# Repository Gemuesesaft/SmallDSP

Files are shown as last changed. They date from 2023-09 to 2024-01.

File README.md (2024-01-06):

# SmallDSP
a small, modular and affordable Audio DSP Module

The goal of this Project is to create a line-up of small DSP modules, centred
around an Analog Devices ADAU1463/67.
This Chip is easy to program with Sigma Studio, a node based development 
environment and pretty powerful for its price.

Current status:
- Dual: Rev 1.1: Layout finished, functionality has to be validated.
- Maxi: Rev 1.0: Layout finished, ,prototype ordered, 
    functionality has to be validated.
- Multi: Rev 1.0: Schematic unfinished.
- Mini: Nothing done yet.
- Micro: Nothing done yet.
- Digi: Nothing done yet.

I've planed for 6 different modules:

- A compact one with two analogue input and output channels (SmallDSP Dual).
- A very small with only digital I2S IOs (SmallDSP Digi).
- A very small module with only one analogue input and output (SmallDSPMini).
- A similar than the Mini, but with and Microphone preamp (SmallDSP Micro). 
    Perhaps powered by phantom power.
- One with 16 analogue IOs (SmallDSP Multi).
- And one with 32 analogue IOs (SmallDSP Maxi).

There are three different versions of the used DSP Chip:
- The ADAU1463WBCPZ150. This is a slower version (max. 150MHz) with 48kWords 
    data memory and 16kWords program memory. Optimal for the smaller Boards
    like the Dual, Mini or Micro.
- The ADAU1463WBCPZ300. This is a faster version (max. 300MHz) with the same
    48kWords data memory and 16kWords program memory. Well suited for heavy
    processing or many channels, for example the Multi or Maxi.
- And the ADAU1467WBCPZ300. This is also a faster version (max. 300MHz) with
    more memory 80kWords data and 24kWords program memory. The expanded memory
    is useful if long delays on multiple channels are required.
All versions are pin-compatible, so one can use the version, best suited for 
the use case. 

The Dual, Digi, Mini and if phantom power isn't possible, the Micro, shall be
powered by a single output wall brick power supply. Both Multi and Maxi are 
using a +-5V power supply and feature a PE connection. They are therefore
designed for a metal enclosure such a 19" Rack enclosure. 

I try to maximize the components covered by JLCPCBs Basic Parts library, so
the boards can be manufactured cheaply and easily. Unfortunately this doesn't
cover all components, so there is still some hand soldering necessary. 

I tried to avoid the use of a Microcontroller, because the DSP can do pretty
much everything on itself. Although the DSP can act as a I2C or SPI master, I 
used ADCs and DAC that are configured directly by setting specific pins,
because the usage of the I2C/SPI master feature an ADAU DSPs is, at least
to my knowledge, not very user-friendly. Please correct me if I'm wrong there 
I would very much like to know an easy way to use this feature.
The Maxi is an exception in that, as it has a STM32 MCU on board. That is 
because the used Codecs are only controllable over I2C/SPI and are way cheaper
than pin-controllable alternatives.

A detailed documentation is planned, but the current focus lies on finishing
the PCBs and the testing of those. Detailed performance measurements will
be published here as well, as soon as they are made.

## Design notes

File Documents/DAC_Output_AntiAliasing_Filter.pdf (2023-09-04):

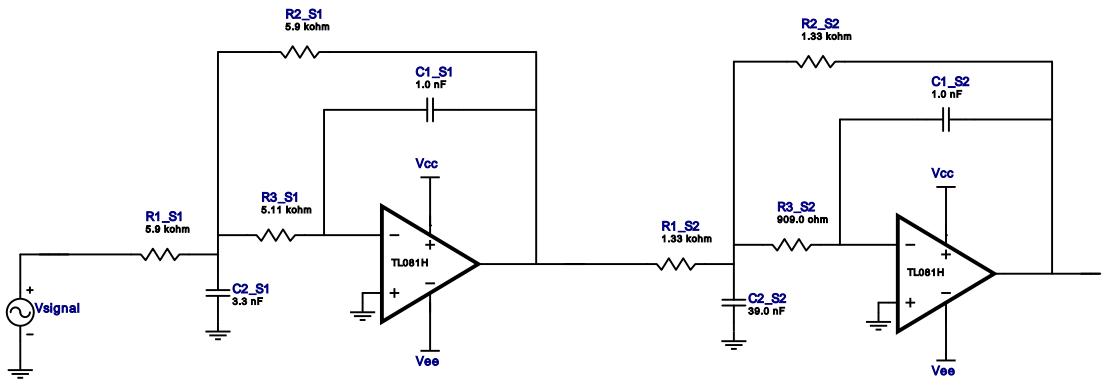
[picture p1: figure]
Vsignal; R1_S1 5.9 kohm; R2_S1 5.9 kohm; R3_S1 5.11 kohm; Vcc; Vee; R1_S2 1.33 kohm; R2_S2 1.33 kohm; R3_S2 909.0 ohm

Copyright © 2023, Texas Instruments Incorporated | 1
Filter Design Report | Lowpass Filter - 4th order Chebyshev | September 3, 2023 10:54:27 GMT-05:00

## Filter Design Report

Design : Lowpass Filter - 4th order Chebyshev Design ID: 142

Type : Lowpass
Response : Chebyshev
Order : 4
Number of Stages : 2

## Electrical BOM

# Name | Manufacturer | Part Number | Properties | Qty

1. A1_S1 | Texas Instruments Inc. | TL081H | GbwTyp= 5.25MHz VccMax= 40V VccMin= 4.5V | 1
2. A1_S2 | Texas Instruments Inc. | TL081H | GbwTyp= 5.25MHz VccMax= 40V VccMin= 4.5V

1

3. C1_S1 | Generic | Ideal | Cap= 1.0 nF Tolerance= 5.0 %

1

4. C1_S2 | Generic | Ideal | Cap= 1.0 nF Tolerance= 5.0 %

1

5. C2_S1 | Generic | Ideal | Cap= 3.3 nF Tolerance= 5.0 %

1

6. C2_S2 | Generic | Ideal | Cap= 39.0 nF Tolerance= 5.0 %

1

7. R1_S1 | Generic | Ideal | Res= 5900.0ohm Tolerance= 1%

1

8. R1_S2 | Generic | Ideal | Res= 1330.0ohm Tolerance= 1%

1

9. R2_S1 | Generic | Ideal | Res= 5900.0ohm Tolerance= 1%

1

10. R2_S2 | Generic | Ideal | Res= 1330.0ohm Tolerance= 1%

1

11. R3_S1 | Generic | Ideal | Res= 5110.0ohm Tolerance= 1%

1

12. R3_S2 | Generic | Ideal | Res= 909.0ohm Tolerance= 1%

1

## Sensitivity Analysis

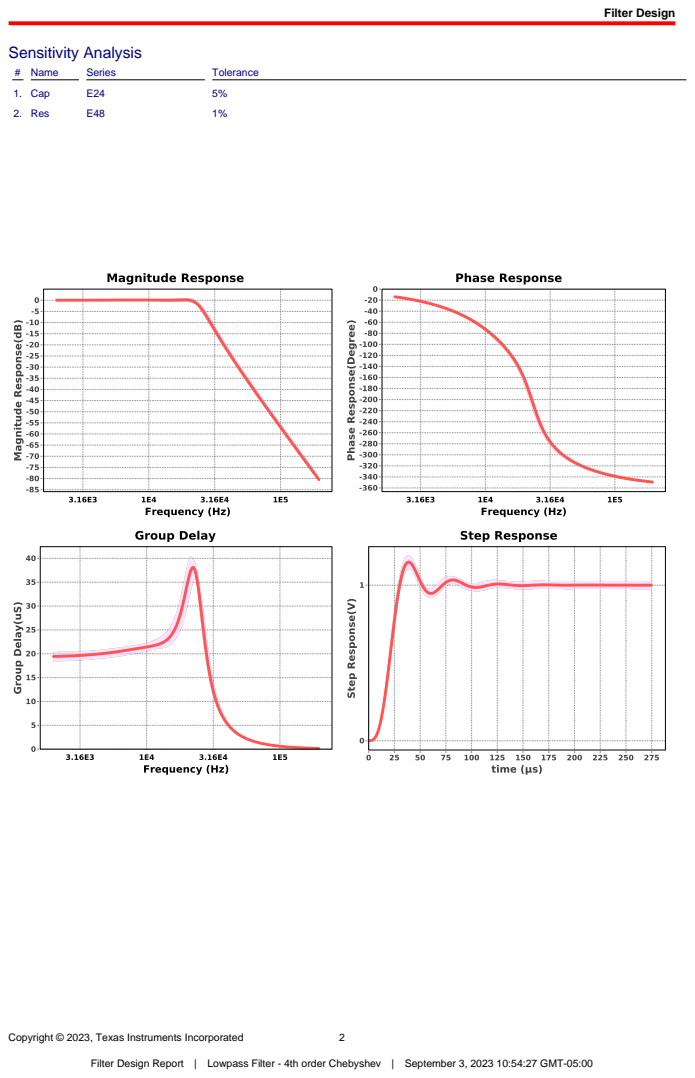
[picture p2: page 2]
Filter Design; # Name; Series; Tolerance; 1. Cap; 2. Res

## Design Inputs

# | Name | Value | Description

1. FilterType | lowpass
2. FilterResponse | Chebyshev
3. FilterOrder | 4.0
4. FilterTopology | Multiple Feedback
5. NumberOfStages | 2.0
6. PassbandFrequency | 20.0 k
7. StopbandAttenuation | -81.546
8. StopbandFrequency | 200.0 k
9. Gain | 1.0
10. DualSupply | +/-5.00 V | Power supply(s) to active chips
11. ResistorTolerance | E48 | Resistor series - 1% Passive resistor tolerance
12. CapacitorTolerance | E24 | Capacitor series - 5% Passive capacitor tolerance

## Design Assistance

1. TL081H Product Folder : http://www.ti.com/product/TL081H : contains the data sheet and other resources.

# Filter Stage :1

Cutoff Frequency | 15.956 kHz
Min GBW Reqd | 976.82 kHz
Stage Gain | 1.0 V/V
Stage Q | 618.769 m
Stage Topology | Multiple Feedback
| R2_S1 5.9 kohm

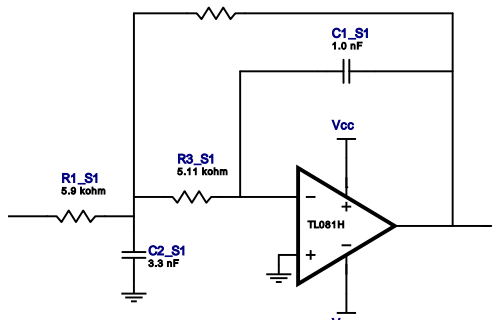
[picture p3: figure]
R1_S1 5.9 kohm; R3_S1 5.11 kohm; Vcc

Vee

## Electrical BOM

# Name | Manufacturer | Part Number | Properties | Qty

1. A1_S1 | Texas Instruments Inc. | TL081H | GbwTyp= 5.25MHz VccMax= 40V VccMin= 4.5V | 1
2. C1_S1 | Generic | Ideal | Cap= 1.0 nF Tolerance= 5.0 %

1

3. C2_S1 | Generic | Ideal | Cap= 3.3 nF Tolerance= 5.0 %

1

4. R1_S1 | Generic | Ideal | Res= 5900.0ohm Tolerance= 1%

1

5. R2_S1 | Generic | Ideal | Res= 5900.0ohm Tolerance= 1%

1

6. R3_S1 | Generic | Ideal | Res= 5110.0ohm Tolerance= 1%

1

# Filter Stage :2

Cutoff Frequency | 23.178 kHz
Min GBW Reqd | 5.035 MHz
Stage Gain | 1.0 V/V
Stage Q | 2.181
Stage Topology | Multiple Feedback
| R2_S2 1.33 kohm

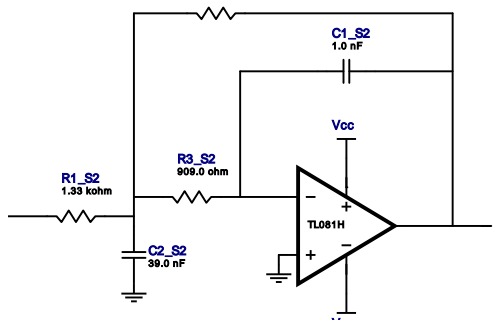
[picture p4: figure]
R1_S2 1.33 kohm; R3_S2 909.0 ohm; Vcc

Vee

## Electrical BOM

# Name | Manufacturer | Part Number | Properties | Qty

1. A1_S2 | Texas Instruments Inc. | TL081H | GbwTyp= 5.25MHz VccMax= 40V VccMin= 4.5V | 1
2. C1_S2 | Generic | Ideal | Cap= 1.0 nF Tolerance= 5.0 %

1

3. C2_S2 | Generic | Ideal | Cap= 39.0 nF Tolerance= 5.0 %

1

4. R1_S2 | Generic | Ideal | Res= 1330.0ohm Tolerance= 1%

1

5. R2_S2 | Generic | Ideal | Res= 1330.0ohm Tolerance= 1%

1

6. R3_S2 | Generic | Ideal | Res= 909.0ohm Tolerance= 1%

1

Important Notice and Disclaimer

TI provides technical and reliability data (including datasheets), design resources (including reference designs), application or other design advice, web tools, safety information, and other resources AS IS and with all faults, and disclaims all warranties. These resources are intended for skilled developers designing with TI products. You are solely responsible for (1) selecting the appropriate TI products for your application, (2) designing, validating and testing your application, and (3) ensuring your application meets applicable standards, and any other safety, security, or other requirements.

These resources are subject to change without notice. TI grants you permission to use these resources only for development of an application that uses the TI products described in the resource. Other reproduction and display of these resources is prohibited. No license is granted to any other TI intellectual property right or to any third party intellectual property right. TI disclaims responsibility for, and you will fully indemnify TI and its representatives against, any claims, damages, costs, losses, and liabilities arising out of your use of these resources.

Providing these resources does not expand or otherwise alter TI's applicable Terms of Sale or other applicable terms available either on ti.com or provided in conjunction with TI products.

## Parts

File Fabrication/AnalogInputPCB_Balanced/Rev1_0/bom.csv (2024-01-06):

Designator | Footprint | Quantity | Value | LCSC Part #
C1, C13, C2, C22, C23, C24, C25, C3, C4 | 0402 | 9 | 100n | C307331
C10, C11, C12, C30, C31, C32, C33, C9 | 0402 | 8 | 330p | C13533
C14, C15, C16, C17, C34, C35, C36, C37 | 0603 | 8 | 33n | C21117
C18, C19, C20, C21, C26, C27, C28, C29, C38, C39, C40, C41, C5, C6, C7, C8 | 1206 | 16 | 10u | C13585
D1, D13, D14, D15, D16, D2, D3, D4 | DFN1006-2 | 8 | H5VL10B | C7420372
D10, D11, D12, D17, D18, D19, D20, D21, D22, D23, D24, D5, D6, D7, D8, D9 | D_SOD-323 | 16 | SD103AWS | C7420360
H1, H2 | MountingHole_3.2mm_M3_Pad_Via | 2 | MountingHole_Pad | -
J1, J2 | IDC-Header_2x10_P2.54mm_Vertical | 2 | IDC | -
J3, J4, J5, J6 | Jack_XLR_Neutrik_NC3FAAH2_Horizontal | 4 | XLR3_Ground
R1, R18, R19, R2, R20, R21, R3, R4 | 0402 | 8 | 100k | C25741
R10, R11, R12, R13, R26, R27, R28, R29, R9 | 0402 | 9 | 10k | C25744
R14, R15, R16, R17, R30, R31, R32, R33 | 0402 | 8 | 47R | C25118
R22, R23, R24, R25, R5, R6, R7, R8 | 0402 | 8 | 20k | C25765
U1, U2, U3, U4 | SOIC-8_3.9x4.9mm_P1.27mm | 4 | NE5532 | C7426

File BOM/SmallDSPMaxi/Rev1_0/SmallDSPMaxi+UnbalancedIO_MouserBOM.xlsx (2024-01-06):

Reference | Manufacturer | Part Number | Qty | Qty total
Mainboard |  |  | 5
C4 | Murata Electronics | GRM1885C1H562JA01D | 1 | 5
FB1-FB4 | Würth Elektronik | 78279220601 | 4 | 20
J11 | Würth Elektronik | 61201021721 | 1 | 5
J12 | JST | B4P-VH | 1 | 5
J13, J15, J17, J19 | Amphenol | T821120A1S100CEU | 4 | 20
J14, J16, J18, J20 | Amphenol | 75869-302LF | 4 | 20
J23 | Amphenol FCI | 20021111-00014T1LF | 1 | 5
JP1 | 3M Electronic Solutions Division | 2303-6111TG | 1 | 5
Q1 | onsemi | NSS1C300ET4G | 1 | 5
SW1 | E-Switch | EG4208A | 1 | 5
U2 | Analog Devices | ADAU1467WBCPZ300 | 1 | 5
U6 | Analog Devices | ADM811TARTZ-REEL | 1 | 5
U5 | STMicroelectronics | M95M01-RMN6TP | 1 | 5
U10-U17 | AKM(Asahi Kasei Microdevices) | AK4619 | 8 | 40
U7 | STMicroelectronics | LD1085D2T33TR | 1 | 5
U8 | Texas Instruments | TLV1117-33 | 1 | 5
U9 | Microchip | PL123-09OC | 1 | 5
Input Board |  |  | 5
J1 | Amphenol | T821120A1S100CEU | 1 | 5
J2-J5 | Kobiconn | 156-4219-E | 4 | 20
Output Board |  |  | 5
J1 | Amphenol | 75869-302LF | 1 | 5
J2-J5 | Kobiconn | 156-4219-E | 4 | 20
PSU |  |  | 1
- | Mean Well | PD2505 | 1 | 1

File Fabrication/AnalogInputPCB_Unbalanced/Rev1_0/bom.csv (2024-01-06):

Designator | Footprint | Quantity | Value | LCSC Part #
C1, C13, C2, C26, C27, C28, C29, C3, C4 | 0402 | 9 | 100n | C307331
C10, C11, C12, C34, C35, C36, C37, C9 | 0402 | 8 | 330p | C13533
C14, C15, C16, C17, C38, C39, C40, C41 | 0603 | 8 | 33n | C21117
C18, C19, C20, C21, C22, C23, C24, C25, C30, C31, C32, C33, C42, C43, C44, C45, C46, C47, C48, C49, C5, C6, C7, C8 | 1206 | 24 | 10u | C13585
D1, D13, D14, D15, D16, D2, D3, D4 | DFN1006-2 | 8 | H5VL10B | C7420372
D10, D11, D12, D17, D18, D19, D20, D21, D22, D23, D24, D5, D6, D7, D8, D9 | D_SOD-323 | 16 | SD103AWS | C7420360
H1, H2 | MountingHole_3.2mm_M3_Pad_Via | 2 | MountingHole_Pad | -
J1 | IDC-Header_2x10_P2.54mm_Vertical | 1 | IDC | -
J2, J3, J4, J5 | Kobiconn_156-4219-E | 4 | RCA x2 | -
R1, R18, R19, R2, R20, R21, R3, R4 | 0402 | 8 | 100k | C25741
R10, R11, R12, R13, R26, R27, R28, R29, R9 | 0402 | 9 | 10k | C25744
R14, R15, R16, R17, R30, R31, R32, R33 | 0402 | 8 | 47R | C25118
R22, R23, R24, R25, R5, R6, R7, R8 | 0402 | 8 | 20k | C25765
U1, U2, U3, U4 | SOIC-8_3.9x4.9mm_P1.27mm | 4 | NE5532 | C7426

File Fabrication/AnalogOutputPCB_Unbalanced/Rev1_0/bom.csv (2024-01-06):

Designator | Footprint | Quantity | Value | LCSC Part #
C1, C13, C14, C15, C16, C2, C22, C23, C24, C25, C3, C34, C35, C36, C37, C4 | 1206 | 16 | 10u | C13585
C10, C11, C12, C30, C31, C32, C33, C9 | 0603 | 8 | 33n | C21117
C17, C18, C19, C20, C21, C38, C39, C40, C41 | 0402 | 9 | 100n | C307331
C26, C27, C28, C29, C5, C6, C7, C8 | 0402 | 8 | 330p | C13533
D1, D2, D3, D4, D5, D6, D7, D8 | DFN1006-2 | 8 | H5VL10B | C7420372
H1, H2 | MountingHole_3.2mm_M3_Pad_Via | 2 | MountingHole_Pad | -
J1 | IDC-Header_2x07_P2.54mm_Vertical | 1 | IDC | -
J2, J3, J4, J5 | Kobiconn_156-4219-E | 4 | RCA x2 | -
R1, R17, R18, R19, R2, R20, R21, R3, R4 | 0402 | 9 | 10k | C25744
R10, R11, R12, R26, R27, R28, R29, R9 | 0402 | 8 | 47R | C25118
R13, R14, R15, R16, R30, R31, R32, R33 | 0402 | 8 | 100k | C25741
R22, R23, R24, R25, R5, R6, R7, R8 | 0402 | 8 | 20k | C25765
U1, U2, U3, U4 | SOIC-8_3.9x4.9mm_P1.27mm | 4 | NE5532 | C7426

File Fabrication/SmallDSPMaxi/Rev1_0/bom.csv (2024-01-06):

Designator | Footprint | Quantity | Value | LCSC Part #
C1, C103, C104, C105, C112, C114, C115, C116, C117, C16, C17, C2, C22, C25, C29, C32, C34, C35, C37, C38, C39, C41, C43, C45, C46, C48, C49, C50, C51, C56, C59, C62, C63, C64, C7, C71, C72, C73, C8, C80, C81, C82, C83, C88, C91, C94, C95, C96 | 0402 | 48 | 100n | C307331
C10, C11, C12, C13, C14, C15, C18, C19, C20 | 0805 | 9 | 22u | C45783
C100, C101, C102, C109, C110, C111, C113, C118, C27, C36, C40, C42, C44, C47, C52, C53, C54, C55, C58, C61, C68, C69, C70, C77, C78, C79, C84, C85, C86, C87, C9, C90, C93 | 0603 | 33 | 10u | C96446
C106, C107, C108, C57, C60, C65, C66, C67, C74, C75, C76, C89, C92, C97, C98, C99 | 0603 | 16 | 4u7 | C19666
C119, C120, C5, C6 | 0402 | 4 | 27p | C1557
C21, C24, C28, C31 | 0402 | 4 | 1u | C52923
C23, C26, C30, C33 | 0402 | 4 | 10n | C15195
C3 | 0402 | 1 | 150p | C1527
C4 | 0603 | 1 | 5n6 | -
D1 | PinHeader_1x02_P1.27mm_Vertical | 1 | LED | -
FB1, FB2, FB3, FB4, FB5 | 0805 | 5 | 600R@100MHz | -
H1, H2, H3, H4 | MountingHole_3.2mm_M3_Pad_Via | 4 | MountingHole | -
J12 | JST_VH_B4P-VH_1x04_P3.96mm_Vertical | 1 | B4P-VH | -
J13, J15, J17, J19 | IDC-Header_2x10_P2.54mm_Vertical | 4 | IDC | -
J14, J16, J18, J20 | IDC-Header_2x07_P2.54mm_Vertical | 4 | IDC | -
J23 | PinHeader_2x07_P1.27mm_Vertical | 1 | Header | -
J7 | IDC-Header_2x05_P2.54mm_Horizontal | 1 | Programming | -
JP1 | SolderJumper-2_P1.3mm_Open_RoundedPad1.0x1.5mm | 1 | SolderJumper_2_Open | -
JP2 | PinHeader_1x03_P2.54mm_Vertical | 1 | Jumper | -
Q1 | TO-252-2 thermal vias | 1 | NSS1C300ET4G | -
Q2, Q3, Q4 | SOT-23 | 3 | 2N7002 | C8545
R1, R38, R85, R88, R91 | 0402 | 5 | 100k | C25741
R10, R11, R12, R13, R14, R15, R16, R17, R18, R19, R20, R21, R22, R23, R24, R25, R26, R3, R35, R4, R45, R46, R47, R48, R49, R5, R50, R51, R52, R53, R54, R55, R56, R57, R58, R59, R6, R60, R61, R62, R63, R64, R65, R66, R67, R68, R7, R8, R80, R81, R9 | 0402 | 51 | 33R | C25105
R2, R27, R69, R70, R71, R73, R74, R76, R77, R78, R79, R82, R83 | 0402 | 13 | 10k | C25744
R28, R29, R30, R31, R33, R34, R43, R44 | 0402 | 8 | 1k | C11702
R36, R84, R87, R90 | 0402 | 4 | 100R | C25076
R37 | 0603 | 1 | 4k3 | C23159
R39, R40, R41, R42 | 0402 | 4 | 1R | C25086
R72, R75 | 0402 | 2 | 2k2 | C25879
SW1 | EG4208 | 1 | SW_4PDT | -
SW2, SW3 | TS-1187A-B-A-B | 2 | TS-1187A-B-A-B | C318884
TP10, TP11, TP12, TP13, TP14, TP15, TP16, TP17, TP18, TP19, TP20, TP21, TP22, TP23, TP24, TP25, TP26, TP4, TP5, TP6, TP7, TP8, TP9 | TestPoint_Pad_D1.0mm | 23 | TestPoint | -
U1, U18, U20, U3, U4 | Diodes_UDFN-10_1.0x2.5mm_P0.5mm | 5 | H5VU25U | C7420374
U10, U11, U12, U13, U14, U15, U16, U17 | QFN-32-1EP_5x5mm_P0.5mm_EP3.7x3.7mm_ThermalVias | 8 | AK4619 | -
U19 | LQFP-48_7x7mm_P0.5mm | 1 | STM32F030C8Tx | C23922
U2 | ADAU1463 | 1 | ADAU1467 | -
U5 | SOIC-8_3.9x4.9mm_P1.27mm | 1 | M95M01-R | -
U6 | SOT-143_Handsoldering | 1 | ADM811 | -
U7 | TO-263-2 | 1 | LD1085D2T33TR | -
U8 | SOT-223-3_TabPin2 | 1 | TLV1117-33 | -
U9 | TSSOP-16_4.4x5mm_P0.65mm | 1 | PL123-09OC | -
Y1 | Crystal_SMD_3225-4Pin_3.2x2.5mm | 1 | 830105957509 | -
Y2 | Crystal_SMD_5032-2Pin_5.0x3.2mm | 1 | 8MHz | C115962

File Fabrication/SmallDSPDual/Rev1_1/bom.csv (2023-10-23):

Designator | Footprint | Quantity | Value | LCSC Part #
C1, C17, C18, C19, C2, C26, C27, C33, C48, C49, C50, C51, C60, C63, C67, C7, C70, C72, C73, C75, C76, C77, C79, C81 | 0402 | 24 | 100n
C10, C11, C12, C36, C37, C9 | 0402 | 6 | 100p
C13, C14, C15, C16, C23, C24, C31, C32 | 1206 | 8 | 1u
C20, C21, C40, C41, C42, C43 | 0402 | 6 | 22p
C22, C25, C28, C29, C30, C65, C74, C78, C8, C80 | 0603 | 10 | 10u
C3 | 0402 | 1 | 150p
C34, C35, C38, C39 | 0603 | 4 | 1n
C4 | 0603 | 1 | 5n6
C44, C45, C46, C47 | 1206 | 4 | 10u
C5, C6 | 0402 | 2 | 27p
C52, C53, C54, C55, C56, C57, C58 | 0805 | 7 | 1u
C59, C62, C66, C69 | 0402 | 4 | 1u
C61, C64, C68, C71 | 0402 | 4 | 10n
D1, D10, D11, D12, D13, D14, D15, D2, D3, D4, D5, D6, D8, D9 | D_SMB | 14 | P6SMB6.8CA
D16, D17, D18, D19, D20, D7 | 0603 | 6 | LED
FB1, FB2, FB3, FB4, FB5, FB6, FB7, FB8, FB9 | 0805 | 9 | 600R@100MHz
H1, H2, H3, H4 | MountingHole_3.2mm_M3_ISO7380 | 4 | MountingHole
J1 | PinHeader_1x05_P1.27mm_Vertical | 1 | Header
J10 | PinHeader_1x02_P1.27mm_Vertical | 1 | Header
J11 | IDC-Header_2x05_P2.54mm_Horizontal | 1 | Programming
J12, J13 | Jack_XLR_Neutrik_NC3FAAH2_Horizontal | 2 | NC3FAAH2
J14, J15 | Jack_XLR_Neutrik_NC3MAAH_Horizontal | 2 | NC3MAAH
J16 | BarrelJack_CUI_PJ-079BH_Horizontal | 1 | Barrel_Jack_Switch
J2, J3 | PinHeader_2x09_P1.27mm_Vertical | 2 | Header
J4 | PinHeader_1x04_P1.27mm_Vertical | 1 | Header
J5, J6 | PinHeader_2x05_P1.27mm_Vertical | 2 | Header
J7, J9 | PinHeader_2x03_P1.27mm_Vertical | 2 | Header
J8 | PinHeader_2x04_P1.27mm_Vertical | 1 | Header
JP1, JP2 | SolderJumper-3_P1.3mm_Bridged12_RoundedPad1.0x1.5mm | 2 | Jumper
JP3, JP4 | SolderJumper-2_P1.3mm_Open_RoundedPad1.0x1.5mm | 2 | Jumper
JP5, JP6 | SolderJumper-2_P1.3mm_Bridged_RoundedPad1.0x1.5mm | 2 | Jumper
Q1 | TO-252-2 | 1 | NSS1C300ET4G
Q2, Q3 | SOT-23 | 2 | MMBT3904
R1, R10, R11, R12, R17, R2, R24, R25, R26, R27, R3, R4, R40, R41, R42, R5, R6, R7, R8, R9 | 0402 | 20 | 100R
R14, R16, R19, R72, R73, R74, R75 | 0402 | 7 | 1k
R15, R36, R37, R38, R39, R45, R52, R53, R54, R55, R56, R57, R58, R59 | 0402 | 14 | 10k
R18 | 0603 | 1 | 4k3
R20, R21, R22, R23, R28, R29, R30, R31, R43, R44 | 0402 | 10 | 100k
R32, R33, R34, R35, R60, R61, R62, R63, R64, R65, R66, R67 | 0402 | 12 | 20k
R46, R47, R80 | 0603 | 3 | 3k6
R48, R49 | 0402 | 2 | 18k
R50, R51 | 0402 | 2 | 5k1
R68, R69, R70, R71 | 0402 | 4 | 47R
R76, R79, R83 | 0402 | 3 | 1k2
R77 | 0402 | 1 | 8k2
R78 | 0603 | 1 | 1k5
R81 | 0603 | 1 | 430R
R82, R84 | 0603 | 2 | 2k
R85 | 0603 | 1 | 240R
R86 | 0603 | 1 | 82R
R87, R88 | 0402 | 2 | 1R
RV1, RV2 | Potentiometer_Nidec_ST4ETB_Vertical | 2 | 1k
SW1 | TS-1187A-B-A-B | 1 | TS-1187A-B-A-B
SW2 | CJS-1201TB | 1 | CJS-1201TB
TP1, TP2 | TestPoint_Keystone_5019_Minature | 2 | TestPoint
TP3, TP4, TP5, TP6, TP7 | TestPoint_Pad_D1.0mm | 5 | TestPoint_Small
U1 | ADAU1463 | 1 | ADAU1463
U10 | SSOP-16_3.9x4.9mm_P0.635mm | 1 | PCM1754
U11, U12, U4, U5, U6, U8, U9 | SOIC-8_3.9x4.9mm_P1.27mm | 7 | NE5532
U13, U14, U15 | TO-252-2 | 3 | LM317_TO-252
U2 | SOT-143_Handsoldering | 1 | ADM811
U3 | SOIC-8_3.9x4.9mm_P1.27mm | 1 | M95M01-R
U7 | TSSOP-14_4.4x5mm_P0.65mm | 1 | PCM1808
Y1 | Crystal_SMD_3225-4Pin_3.2x2.5mm | 1 | 830105957509

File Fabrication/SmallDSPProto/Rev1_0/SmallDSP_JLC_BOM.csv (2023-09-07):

Designator | Footprint | Qty | Value | LCSC Part #
C1, C2, C7, C17, C18, C19, C25, C26, C27, C31, C32, C42, C43, C46, C60, C63, C67, C70, C72, C73, C75, C76, C77, C79, C81" | 0402 | 25 | 100n | C1525
C3 | 0402 | 1 | 150p | C1527
C5, C6 | 0402 | 2 | 27p | C1557
C8, C24, C28, C29, C30, C35, C65, C74, C78, C80 | 0603 | 10 | 10u | C96446
C13, C14, C15, C16, C22, C23 | 1206 | 6 | 1u | C1848
C20, C21, C47, C48 | 0402 | 4 | 22p | C1555
C33, C34, C49, C50, C51, C52 | 1206 | 6 | 10u | C13585
C53, C54, C55, C56, C57, C58 | 0805 | 6 | 1u | C28323
C59, C62, C66, C69 | 0402 | 4 | 1u | C52923
C61, C64, C68, C71 | 0402 | 4 | 10n | C15195
D3, D10, D12, D13, D14 | 0603 | 5 | LED | C72041
Q2, Q3 | SOT-23 | 2 | MMBT3904 | C20526
R1, R2, R3, R4, R5, R6, R7, R8, R9, R10, R11, R12, R17, R24, R25, R26, R27, R40, R41, R42, R71 | 0402 | 21 | 100R | C25076
R13, R15, R28, R29, R30, R31 | 0402 | 6 | 100k | C25741
R14, R16, R19 | 0402 | 3 | 1k | C11702
R20, R21, R22, R23 | 0402 | 4 | 1Meg | C26083
R32, R33, R34, R35, R36, R37, R38, R39, R43, R56, R57, R58, R59 | 0402 | 13 | 4k7 | C25900
R60, R61, R62, R63 | 0402 | 4 | 10R | C25077
R65 | 0603 | 1 | 390R | C23151
R66 | 0402 | 1 | 470R | C25117
R67 | 0402 | 1 | 1k2 | C25862
R68 | 0402 | 1 | 120R | C25079
R70 | 0402 | 1 | 150R | C25082
SW1 | TS-1187A-B-A-B | 1 | TS-1187A-B-A-B | C318884
U4, U5, U6, U9, U10, U11 | SOIC-8 | 6 | NE5532 | C7426
U12, U13 | TO-252 | 2 | LM317_TO-252 | C75510

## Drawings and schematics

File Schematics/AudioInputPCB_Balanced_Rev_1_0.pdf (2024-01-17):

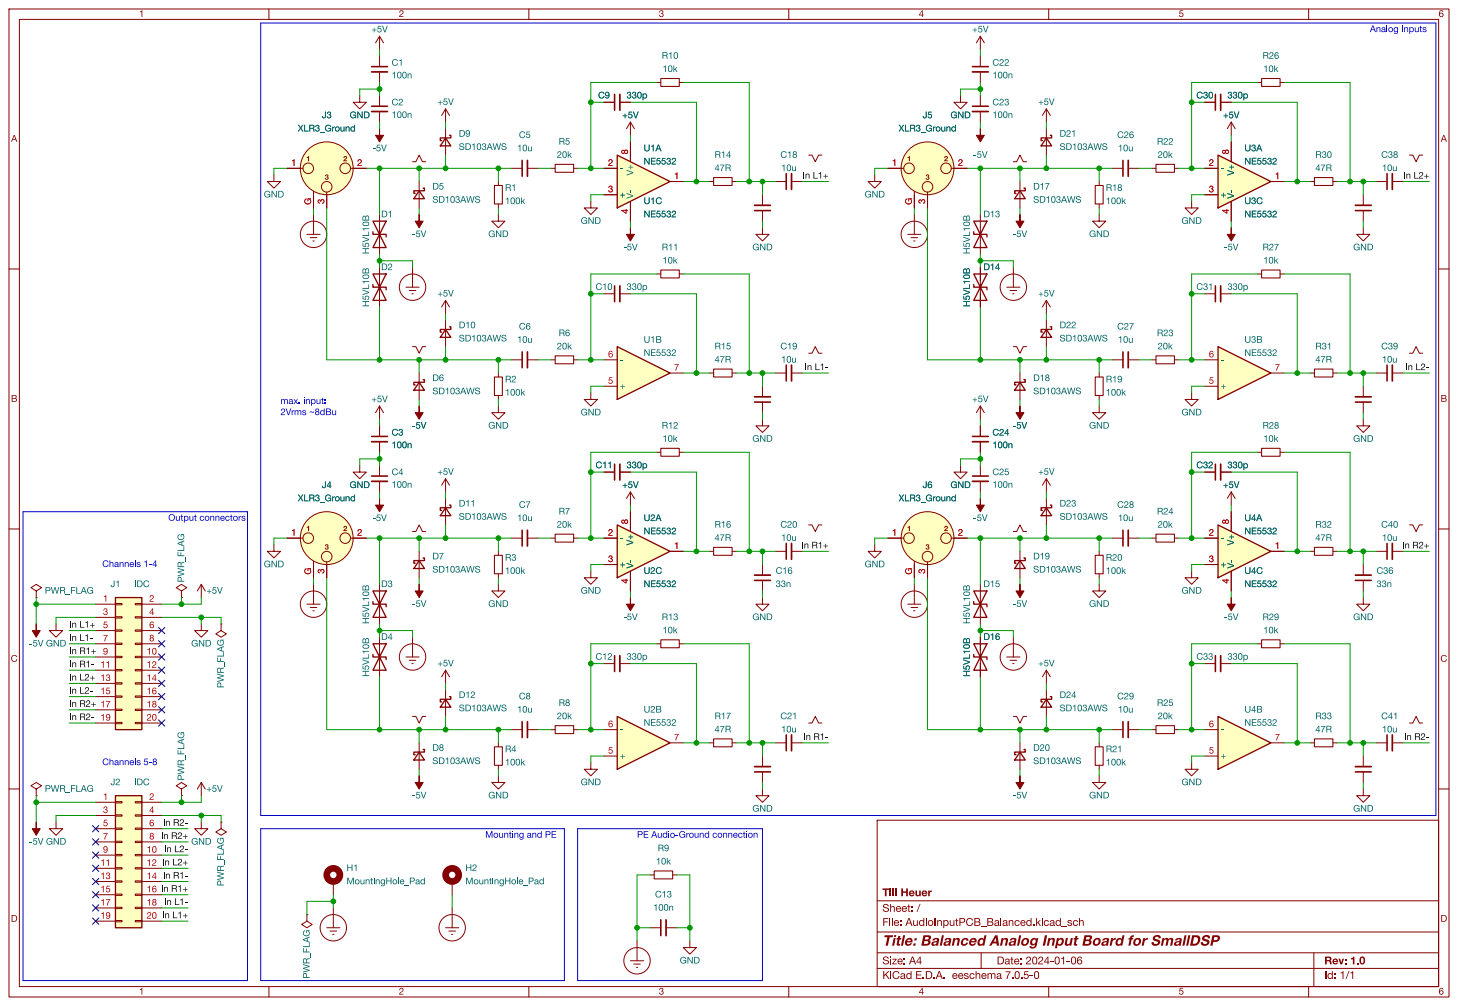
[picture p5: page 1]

File: AudioInputPCB_Balanced.kicad_sch Sheet: / Till Heuer R3

Id: 1/1 Title: Balanced Analog Input Board for SmallDSP

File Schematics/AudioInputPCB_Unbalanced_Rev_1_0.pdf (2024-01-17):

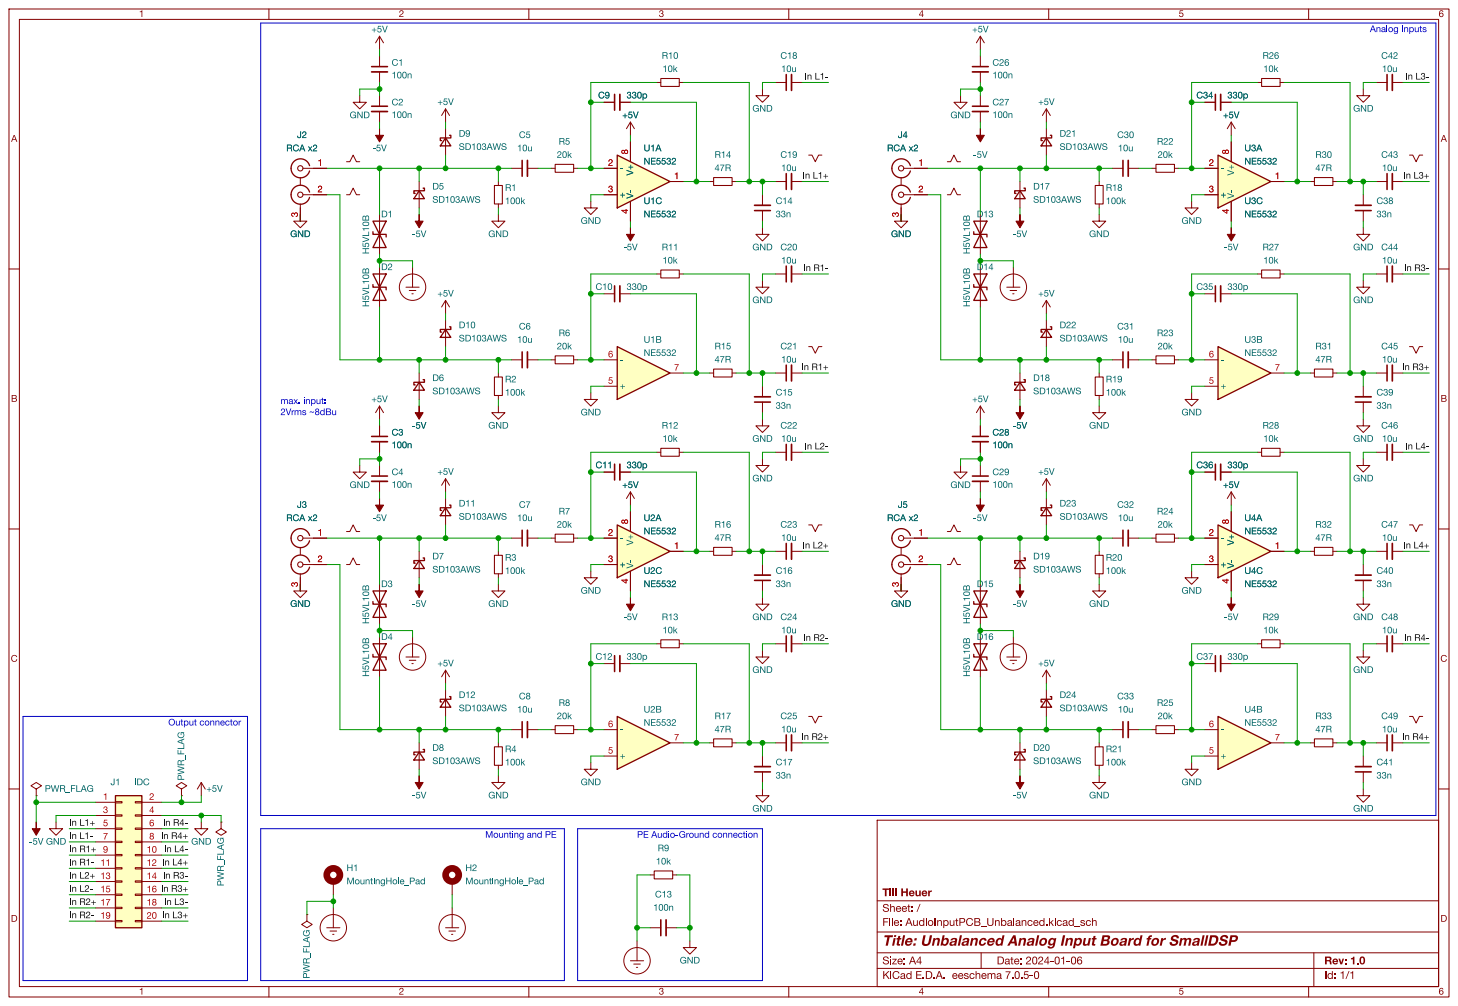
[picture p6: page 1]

Id: 1/1 Title: Unbalanced Analog Input Board for SmallDSP

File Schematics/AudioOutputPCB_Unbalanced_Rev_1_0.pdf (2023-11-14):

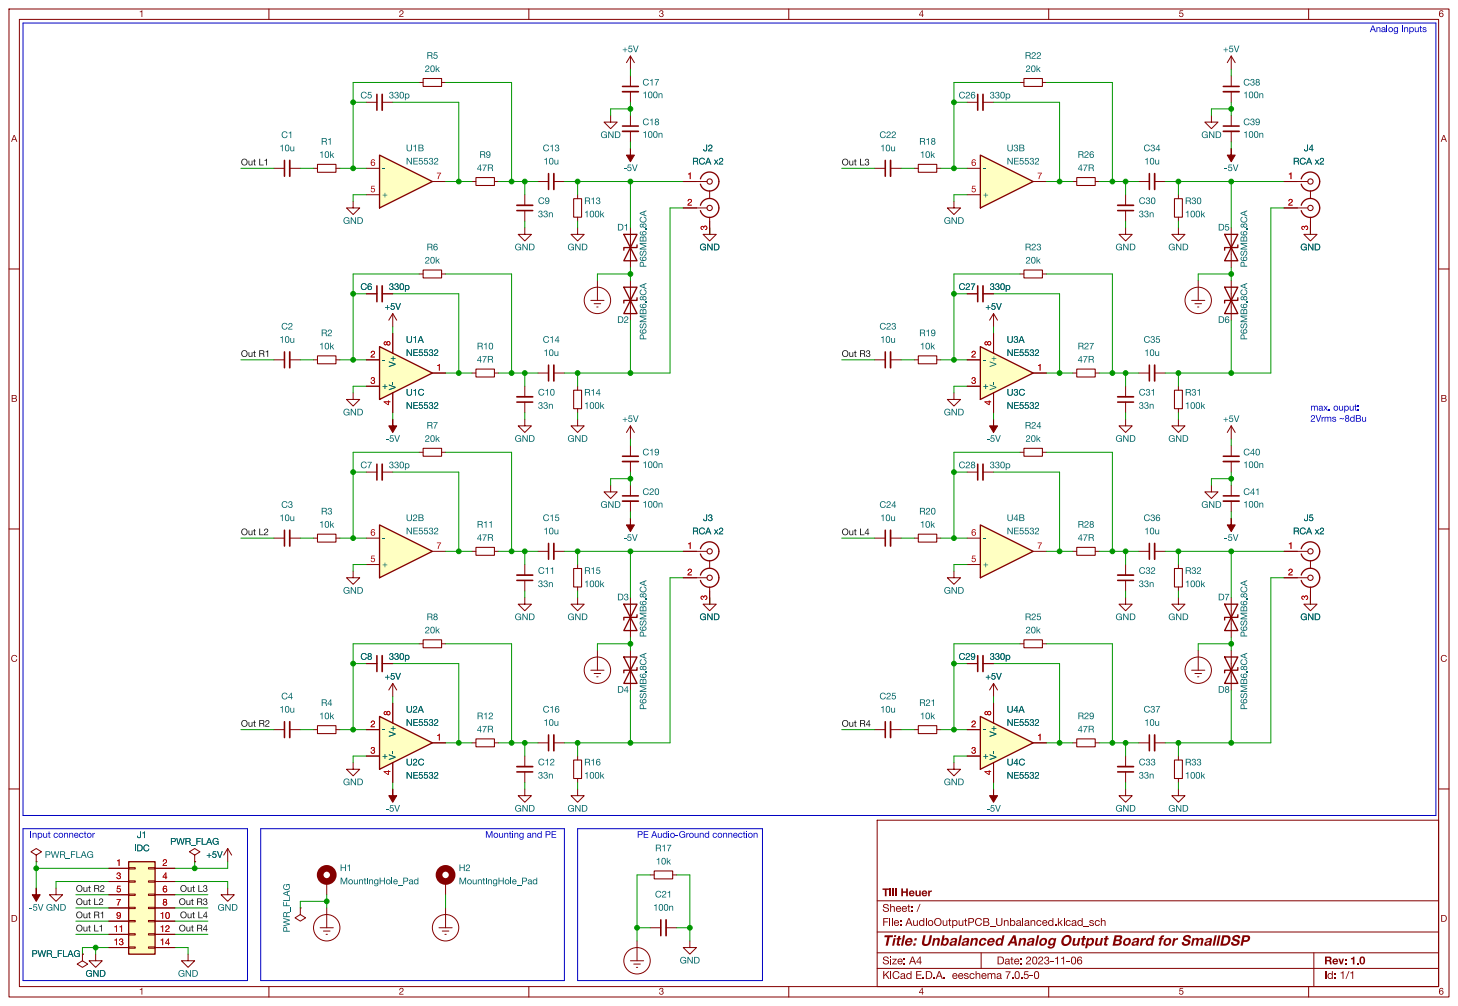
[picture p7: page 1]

Analog Inputs max. ouput: 2Vrms ~8dBu PWR_FLAG
47R GND

File: AudioOutputPCB_Unbalanced.kicad_sch Sheet: / Till Heuer GND

Id: 1/1 Title: Unbalanced Analog Output Board for SmallDSP

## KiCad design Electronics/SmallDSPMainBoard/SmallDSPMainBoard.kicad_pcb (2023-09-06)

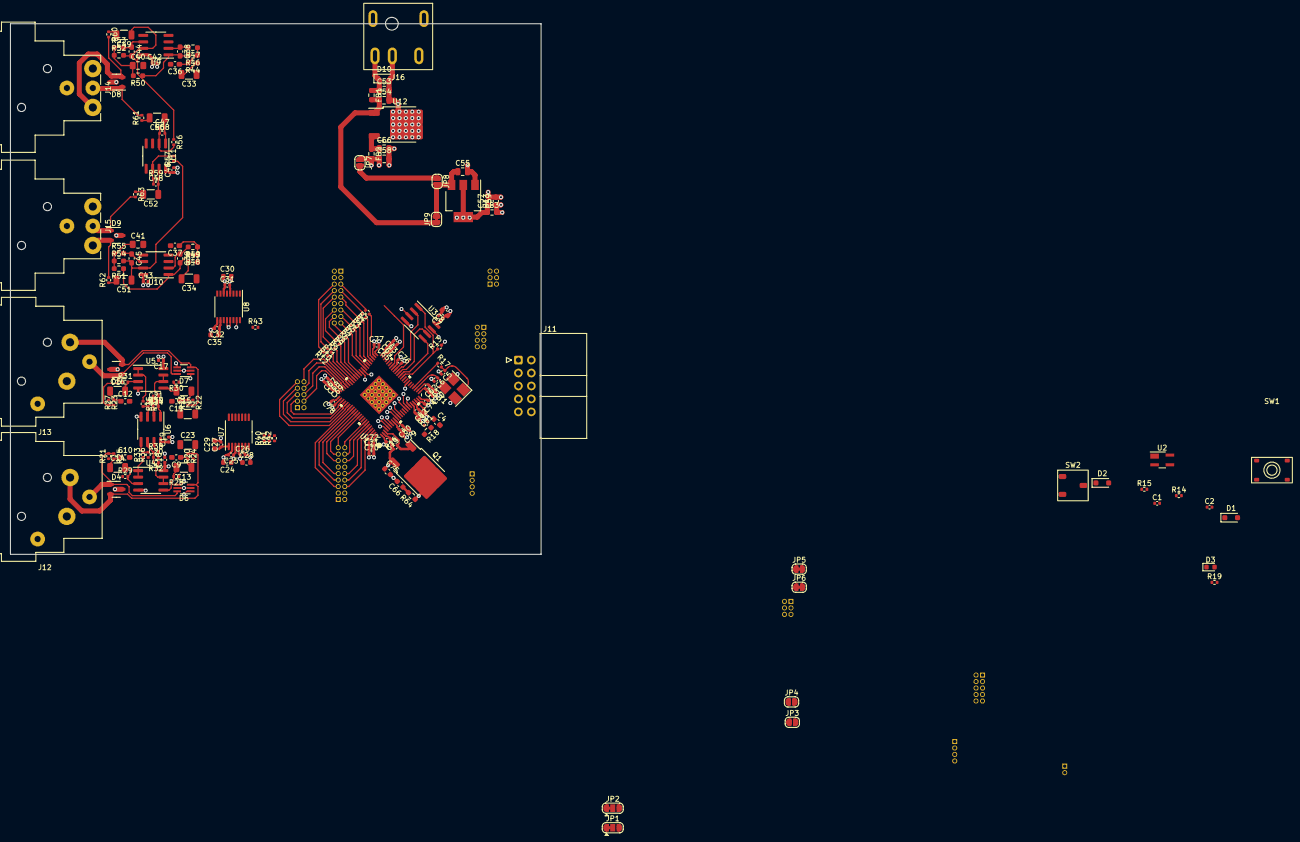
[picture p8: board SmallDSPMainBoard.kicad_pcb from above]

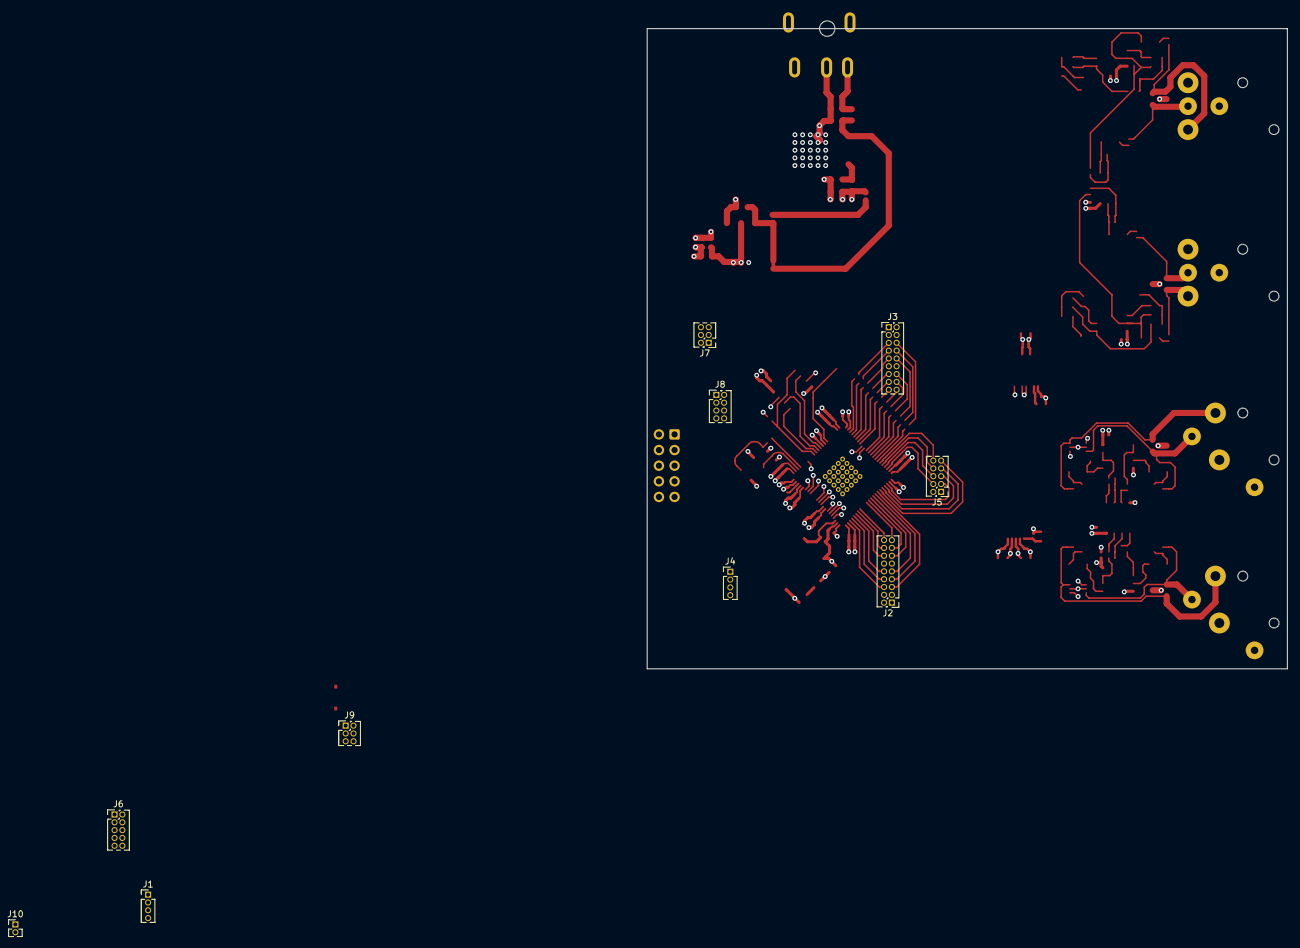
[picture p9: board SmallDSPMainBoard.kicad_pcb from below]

Board: 2 copper layers, 104.0 x 104.0 mm, 201 parts (10 on the bottom side), 155 nets.

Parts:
C1, C2, C7, C17, C18, C19, C25, C26, C27, C31, C32, C42, C43, C46, C61, C64, C68, C71, C73, C74, C76, C77, C78, C80, C82: 100n; C_0402_1005Metric
C3: 150p; C_0402_1005Metric
C4: 5n6; C_0603_1608Metric_Pad1.08x0.95mm_HandSolder
C5, C6: 27p; C_0402_1005Metric
C8, C24, C28, C29, C30, C35, C66, C75, C79, C81: 10u; C_0603_1608Metric
C9, C10, C11, C12, C38, C39, C44, C45: 1n; C_0603_1608Metric_Pad1.08x0.95mm_HandSolder
C13, C14, C15, C16, C22, C23: 1u; C_1206_3216Metric
C20, C21, C47, C48: 22p; C_0402_1005Metric
C33, C34, C49, C50, C51, C52: 10u; C_1206_3216Metric
C36, C37: 3n3; C_0603_1608Metric_Pad1.08x0.95mm_HandSolder
C40, C41: 39n; C_0805_2012Metric_Pad1.18x1.45mm_HandSolder
C53, C54: 330n; C_0805_2012Metric
C55, C56, C58: 1u; C_0805_2012Metric
C57, C59: 2u2; C_0603_1608Metric
C60, C63, C67, C70: 1u; C_0402_1005Metric
C62, C65, C69, C72: 10n; C_0402_1005Metric
D1, D2: STS321033U202; D_SOD-323_HandSoldering
D3: LED; LED_0603_1608Metric
D4, D5, D8, D9: STS232150B251; SOT-23-3
D6, D7: BAT54XY,115; SOT-363_SC-70-6_Handsoldering
D10: STS321360U351; D_SOD-323_HandSoldering
FB1, FB2, FB3: MFBW1V3216-102-R; R_0603_1608Metric_Pad0.98x0.95mm_HandSolder
J1, J4: Header; PinHeader_1x04_P1.27mm_Vertical
J2, J3: Header; PinHeader_2x09_P1.27mm_Vertical
J5, J6: Header; PinHeader_2x05_P1.27mm_Vertical
J7, J9: Header; PinHeader_2x03_P1.27mm_Vertical
J8: Header; PinHeader_2x04_P1.27mm_Vertical
J10: Header; PinHeader_1x02_P1.27mm_Vertical
J11: Programming; IDC-Header_2x05_P2.54mm_Horizontal
J12, J13: NC3FAAH2; Jack_XLR_Neutrik_NC3FAAH2_Horizontal
J14, J15: NC3MAAH; Jack_XLR_Neutrik_NC3MAAH_Horizontal
J16: Barrel_Jack_Switch; BarrelJack_CUI_PJ-079BH_Horizontal
JP1, JP2: Jumper; SolderJumper-3_P1.3mm_Bridged12_RoundedPad1.0x1.5mm
JP3, JP4, JP7, JP8: Jumper; SolderJumper-2_P1.3mm_Open_RoundedPad1.0x1.5mm
JP5, JP6, JP9: Jumper; SolderJumper-2_P1.3mm_Bridged_RoundedPad1.0x1.5mm
Q1: NSS1C300ET4; TO-252-2
R1, R2, R3, R4, R5, R6, R7, R8, R9, R10, R11, R12, R17, R24, R25, R26, R27, R40, R41, R42: 100R; R_0402_1005Metric
R13, R15, R28, R29, R30, R31: 100k; R_0402_1005Metric
R14, R16, R19: 1k; R_0402_1005Metric
R18: 4k3; R_0603_1608Metric_Pad0.98x0.95mm_HandSolder
R20, R21, R22, R23: 1Meg; R_0402_1005Metric
R32, R33, R34, R35, R36, R37, R38, R39, R43, R56, R57, R58, R59: 4k7; R_0402_1005Metric
R44, R45, R46, R48: 5k9; R_0603_1608Metric_Pad0.98x0.95mm_HandSolder
R47, R49: 5k11; R_0603_1608Metric_Pad0.98x0.95mm_HandSolder
R50, R51, R52, R54: 1k33; R_0603_1608Metric_Pad0.98x0.95mm_HandSolder
R53, R55: 909R; R_0603_1608Metric_Pad0.98x0.95mm_HandSolder
R60, R61, R62, R63: 10R; R_0402_1005Metric
R64: 500m; R_0603_1608Metric_Pad0.98x0.95mm_HandSolder
SW1: TS-1187A-B-A-B
SW2: CJS-1201TB
U1: ADAU1463
U2: ADM811; SOT-143_Handsoldering
U3: M95M01-R; SOIC-8_3.9x4.9mm_P1.27mm
U4, U5, U6, U9, U10, U11: NE5532; SOIC-8_3.9x4.9mm_P1.27mm
U7: PCM1808; TSSOP-14_4.4x5mm_P0.65mm
U8: PCM1754; SSOP-16_3.9x4.9mm_P0.635mm
U12: L7805; TO-252-2
U13: TLV76133; SOT-223-3_TabPin2
Y1: 830105957509; Crystal_SMD_3225-4Pin_3.2x2.5mm_HandSoldering

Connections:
+1V2: C60.1, C61.1, C62.1, C63.1, C64.1, C65.1, C67.1, C68.1, C69.1, C70.1, C71.1, C72.1, J1.3, Q1.2 (C), R64.1, U1.24 (DVdd), U1.43 (DVdd), U1.65 (DVdd), U1.87 (DVdd)
+3V3: C2.1, C7.1, C8.1, C26.1, C28.1, C59.1, C73.1, C74.1, C75.1, C76.1, C77.1, C78.1, C79.1, C80.1, C81.1, C82.1, FB3.2, J1.2, J2.2, J3.2, J4.1, J5.2, J6.2, J7.2, J8.2, J9.2, JP1.3 (B), JP2.3 (B), Q1.3 (E), R13.2, R15.2, R16.1, R43.2, SW2.1, U1.2 (IOVdd), U1.9 (AVdd), U1.19 (PLLVdd), U1.22 (IOVdd), U1.37 (IOVdd), U1.46 (IOVdd), U1.68 (IOVdd), U2.4 (Vcc), U3.3 (WriteProt*), U3.7 (Hold*), U3.8 (Vcc), U7.4 (DVdd)
+5V: C17.1, C18.1, C19.1, C24.1, C25.1, C30.1, C31.1, C42.1, C43.1, C46.1, C58.1, D6.2 (K1), D6.5 (K2), D7.2 (K1), D7.5 (K2), FB2.2, J1.1, JP7.1 (A), U4.8 (V+), U5.8 (V+), U6.8 (V+), U7.3 (AVcc), U8.6 (Vcc), U9.8 (V+), U10.8 (V+), U11.8 (V+)
/5V_PGRM: J11.4, R19.1
/Analog Input/Analog_In_L: C21.2, C22.1, R39.2, U6.1
/Analog Input/Analog_In_R: C20.2, C23.1, R38.2, U6.7
/Analog Output/DAC_Out_L: C33.2, R44.1
/Analog Output/DAC_Out_R: C34.2, R45.1
/AuxADC0: J6.3, U1.10 (AuxADC0)
/AuxADC1: J6.5, U1.11 (AuxADC1)
/AuxADC2: J6.7, U1.12 (AuxADC2)
/AuxADC3: J6.9, U1.13 (AuxADC3)
/AuxADC4: J6.10, U1.14 (AuxADC4)
/AuxADC5: J6.8, U1.15 (AuxADC5)
/AuxADC6: J6.6, U1.16 (AuxADC6)
/AuxADC7: J6.4, U1.17 (AuxADC7)
/BCLK_In0: J2.5, R40.2, U1.73 (BCLK_In0)
/BCLK_In1: J2.13, U1.76 (BCLK_In1)
/BCLK_In2: J2.18, U1.81 (BCLK_In2)
/BCLK_In3: J2.10, U1.84 (BCLK_In3)
/BCLK_Out0: J3.7, R1.2, U8.1 (BCLK)
/BCLK_Out1: J3.15, R4.2
/BCLK_Out2: J3.16, R7.2
/BCLK_Out3: J3.8, R10.2
/DAC_Mute: JP5.1 (A), R43.1, U8.14 (Mute)
/DAC_ZeroFlag: JP6.1 (A), U8.11 (ZeroFlag)
/DSP_RST*: R15.1, U1.28 (Reset*), U2.2 (RST*)
/GPIO6: J9.3, U1.53 (GPIO6)
/GPIO7: J9.5, U1.54 (GPIO7)
/GPIO14: J9.6, JP5.2 (B), U1.6 (GPIO14)
/GPIO15: J9.4, JP6.2 (B), U1.7 (GPIO15)
/LRCK_In0: J2.7, R41.2, U1.74 (LRCK_In0/GPIO10)
/LRCK_In1: J2.15, U1.77 (LRCK_In1/GPIO11)
/LRCK_In2: J2.16, U1.82 (LRCK_In2/GPIO12)
/LRCK_In3: J2.8, U1.85 (LRCK_In3/GPIO13)
/LRCK_Out0: J3.5, R2.2, U8.3 (LRCK)
/LRCK_Out1: J3.13, R5.2
/LRCK_Out2: J3.18, R8.2
/LRCK_Out3: J3.10, R11.2
/MCLK: J2.1, J3.1, U1.27 (MCLK_Out), U7.6 (MCLK), U8.16 (MCLK)
/M_CS: J8.8, R13.1, U1.32 (M_CS/GPIO0), U3.1 (CS*)
/M_MOSI: J8.7, U1.33 (M_MOSI/GPIO1), U3.5 (SDI)
/M_SCL1/SCLK: J8.3, U1.34 (M_SCL1/M_SCLK/GPIO2), U3.6 (SCLK)
/M_SDA1/MISO: J8.5, U1.35 (M_SDA1/M_MISO/GPIO3), U3.2 (SDO)
/M_SDA2: J8.6, U1.31 (M_SDA2/GPIO25)
/M_SDL2: J8.4, U1.30 (M_SCL2/GPIO24)
/RST_PGRM: J11.6, R14.2
/SDATA_IO0: J5.9, U1.72 (SDATA_IO0/GPIO16)
/SDATA_IO1: J5.7, U1.71 (SDATA_IO1/GPIO17)
/SDATA_IO2: J5.5, U1.70 (SDATA_IO2/GPIO18)
/SDATA_IO3: J5.3, U1.69 (SDATA_IO3/GPIO19)
/SDATA_IO4: J5.4, U1.64 (SDATA_IO4/GPIO20)
/SDATA_IO5: J5.6, U1.63 (SDATA_IO5/GPIO21)
/SDATA_IO6: J5.8, U1.62 (SDATA_IO6/GPIO22)
/SDATA_IO7: J5.10, U1.61 (SDATA_IO7/GPIO23)
/SDATA_In0: J2.9, R42.2, U1.75 (SDATA_In0)
/SDATA_In1: J2.17, U1.78 (SDATA_In1)
/SDATA_In2: J2.14, U1.83 (SDATA_In2)
/SDATA_In3: J2.6, U1.86 (SDATA_In3)
/SDATA_Out0: J3.9, R3.2, U8.2 (SDATA)
/SDATA_Out1: J3.17, R6.2
/SDATA_Out2: J3.14, R9.2
/SDATA_Out3: J3.6, R12.2
/SPDIT_In: J4.3, U1.4 (SPDIF_In)
/SPDIT_Out: J4.4, U1.5 (SPDIF_Out)
/S_CS: J7.6, JP3.1 (A)
/S_MOSI: J7.4, JP4.1 (A)
/S_SCL: J7.5, J11.1, U1.39 (S_SCL/S_SCLK)
/S_SDA/MISO: J7.3, J11.3, U1.38 (S_SDA/S_MISO)
/Tmp+: J10.1, U1.80 (TempD+)
/Tmp-: J10.2, U1.79 (TempD-)
GND: C1.2, C2.2, C3.1, C5.2, C6.2, C7.2, C8.2, C9.2, C10.2, C11.2, C12.2, C17.2, C18.2, C19.2, C24.2, C25.2, C26.2, C27.2, C28.2, C29.2, C30.2, C31.2, C32.2, C35.2, C36.2, C37.2, C40.2, C41.2, C42.2, C43.2, C46.2, C53.2, C54.2, C55.2, C56.2, C57.2, C58.2, C59.2, C60.2, C61.2, C62.2, C63.2, C64.2, C65.2, C66.2, C67.2, C68.2, C69.2, C70.2, C71.2, C72.2, C73.2, C74.2, C75.2, C76.2, C77.2, C78.2, C79.2, C80.2, C81.2, C82.2, D1.1 (A1), D2.2 (A), D3.1 (K), D4.3 (common), D5.3 (common), D6.1 (A1), D6.4 (A2), D7.1 (A1), D7.4 (A2), D8.3 (common), D9.3 (common), D10.2 (A), J1.4, J2.3, J2.4, J2.11, J2.12, J3.3, J3.4, J3.11, J3.12, J4.2, J5.1, J6.1, J7.1, J8.1, J9.1, J11.10, J12.1, J13.1, J14.1, J14.G, J15.1, J15.G, J16.2, JP1.1 (A), JP2.1 (A), R18.2, R20.1, R21.1, R22.1, R23.1, SW1.1, SW2.3, U1.1 (DGND), U1.8 (AGND), U1.18 (PLLGND), U1.21 (DGND), U1.23 (DGND), U1.29 (DGND), U1.36 (DGND), U1.44 (DGND), U1.45 (DGND), U1.66 (DGND), U1.67 (DGND), U1.88 (DGND), U1.EP, U2.1 (GND), U3.4 (GND), U4.4 (V-), U5.4 (V-), U6.4 (V-), U7.2 (AGND), U7.5 (DGND), U7.10 (Mode0), U7.11 (Mode1), U7.12 (Format), U8.4 (DGND), U8.9 (AGND), U8.12 (Test), U8.13 (DeEmp), U8.15 (Format), U9.4 (V-), U10.4 (V-), U11.4 (V-), U12.2 (GND), U13.1 (GND), Y1.2, Y1.4
unnamed: C4.2, R18.1
unnamed: C5.1, R17.2, Y1.1
unnamed: C10.1, C14.1, R25.2
unnamed: C11.1, C15.1, R26.2
unnamed: C12.1, C16.1, R27.2
unnamed: C9.1, C13.1, R24.2
unnamed: C36.1, R44.2, R46.1, R47.1
unnamed: C37.1, R45.2, R48.1, R49.1
unnamed: C38.2, R46.2, R50.1, U9.1
unnamed: C39.2, R48.2, R51.1, U10.1
unnamed: C40.1, R50.2, R52.1, R53.1
unnamed: C41.1, R51.2, R54.1, R55.1
unnamed: C44.2, C49.1, R52.2, R56.1, U9.7
unnamed: C45.2, C51.1, R54.2, R57.1, U10.7
unnamed: C47.2, C50.1, R58.2, U11.1
unnamed: C48.2, C52.1, R59.2, U11.7
unnamed: C49.2, R60.1
unnamed: C50.2, R61.1
unnamed: C51.2, R62.1
unnamed: C52.2, R63.1
unnamed: C66.1, R64.2
unnamed: C1.1, D1.2 (A2), R14.1, SW1.2, U2.3 (MnRST*)
unnamed: D2.1 (K), SW2.2, U1.42 (Selfboot)
unnamed: D3.2 (A), R19.2
unnamed: D4.1 (A1), D6.6 (C2), J12.3, R21.2, R25.1
unnamed: D4.2 (A2), D6.3 (C1), J12.2, R20.2, R24.1
unnamed: D5.1 (A1), D7.6 (C2), J13.3, R23.2, R27.1
unnamed: D5.2 (A2), D7.3 (C1), J13.2, R22.2, R26.1
unnamed: D8.1 (A1), J14.3, R61.2
unnamed: D8.2 (A2), J14.2, R60.2
unnamed: D9.1 (A1), J15.3, R63.2
unnamed: D9.2 (A2), J15.2, R62.2
unnamed: JP1.2 (C), JP4.2 (B), U1.40 (S_MOSI/AD1)
unnamed: JP2.2 (C), JP3.2 (B), U1.41 (S_CS/AD0)
unnamed: JP7.2 (B), JP8.1 (A)
unnamed: C55.1, JP8.2 (B), JP9.2 (B), U13.3 (IN)
unnamed: C54.1, FB1.2, JP9.1 (A), U12.1 (IN)
unnamed: Q1.1 (B), R16.2, U1.3 (VDrive)
unnamed: C3.2, C4.1, U1.20 (PLLFlt)
unnamed: C6.1, U1.25 (Xtal_In/MCLK_In), Y1.3
unnamed: R17.1, U1.26 (Xtal_Out)
unnamed: R1.1, U1.48 (BCLK_Out0)
unnamed: R4.1, U1.51 (BCLK_Out1)
unnamed: R7.1, U1.56 (BCLK_Out2)
unnamed: R10.1, U1.59 (BCLK_Out3)
unnamed: R2.1, U1.47 (LRCK_Out0/GPIO4)
unnamed: R5.1, U1.50 (LRCK_Out1/GPIO5)
unnamed: R8.1, U1.55 (LRCK_Out2/GPIO8)
unnamed: R11.1, U1.58 (LRCK_Out3/GPIO9)
unnamed: R3.1, U1.49 (SDATA_Out0)
unnamed: R6.1, U1.52 (SDATA_Out1)
unnamed: R9.1, U1.57 (SDATA_Out2)
unnamed: R12.1, U1.60 (SDATA_Out3)
unnamed: C14.2, R29.2, U4.3 (+)
unnamed: R33.1, U4.1, U4.2 (-)
unnamed: C13.2, R28.2, U4.5 (+)
unnamed: R32.1, U4.6 (-), U4.7
unnamed: C16.2, R31.2, U5.3 (+)
unnamed: R35.1, U5.1, U5.2 (-)
unnamed: C15.2, R30.2, U5.5 (+)
unnamed: R34.1, U5.6 (-), U5.7
unnamed: R35.2, R37.2, U6.3 (+)
unnamed: C21.1, R34.2, R39.1, U6.2 (-)
unnamed: R33.2, R36.2, U6.5 (+)
unnamed: C20.1, R32.2, R38.1, U6.6 (-)
unnamed: R40.1, U7.8 (BCLK)
unnamed: C22.2, U7.13 (In_L)
unnamed: C23.2, U7.14 (In_R)
unnamed: R41.1, U7.7 (LRCK)
unnamed: R42.1, U7.9 (SDATA)
unnamed: C27.1, C29.1, U7.1 (Vcom)
unnamed: C33.1, U8.7 (Out_L)
unnamed: C34.1, U8.8 (Out_R)
unnamed: C38.1, R47.2, U9.2 (-)
unnamed: C44.1, R53.2, U9.6 (-)
unnamed: C39.1, R49.2, U10.2 (-)
unnamed: C45.1, R55.2, U10.6 (-)
unnamed: C47.1, R56.2, R58.1, U11.2 (-)
unnamed: C48.1, R57.2, R59.1, U11.6 (-)
unnamed: C56.1, FB2.1, U12.3 (OUT)
unnamed: C57.1, FB3.1, U13.2 (OUT)
VCC: C53.1, D10.1 (K), FB1.1, J16.1
VCOM: C32.1, C35.1, R28.1, R29.1, R30.1, R31.1, R36.1, R37.1, U8.10 (Vcom), U9.3 (+), U9.5 (+), U10.3 (+), U10.5 (+), U11.3 (+), U11.5 (+)

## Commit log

2023-09-05 Adds seperate ground for crystal and pll
    [DSP_Decoupling.kicad_sch, SmallDSPMainBoard.kicad_pcb, SmallDSPMainBoard.kicad_sch]
2023-09-06 Partly finishes layout
    [Analog_Input.kicad_sch, Analog_Output.kicad_sch, DSP_Decoupling.kicad_sch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]
2023-09-07 Finishes layout of Rev 1.0 and fixes a polarity error in the schematic
    [Analog_Input.kicad_sch, Analog_Output.kicad_sch, DSP_Decoupling.kicad_sch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]
2023-09-07 Adds unnessesary files to gitignore and removes them from remote repo
    [JLC_BOM.xlsx, SmallDSP_JLC_BOM.csv, SmallDSP_JLC_BOM.xlsx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]
2023-09-07 Adds additional PCB Text and Logos
    [designators.csv]
2023-10-17 Does some cleaning and adds SmallDSP Maxi, an 32x32 DSP. Also adds unfinished ReadMe.
    [Analog_Input.kicad_sch, Analog_Output.kicad_sch, AudioInputPCB_Unbalanced.kicad_sch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]
2023-10-23 Finishes SmallDSP Maxi plus the fitting In- and Output Boards
    [AudioInputPCB_Unbalanced.kicad_sch, AudioOutputPCB_Unbalanced.kicad_sch, Codecs.kicad_sch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]
2023-10-23 Generates Fabrication files for Maxi, Dual and In- nad Output Boards. Also Updates the ReadMe.
    [Analog_Input.kicad_sch, Analog_Output.kicad_sch, DSP_Decoupling.kicad_sch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]
2023-10-23 replaces 12pin IDC out header with 14pin one because of better availability.
    [AudioOutputPCB_Unbalanced.kicad_sch, Codecs.kicad_sch, MCU.kicad_sch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]
2023-10-28 Fixes schematic mistakes, like incorrect routin of clock to codecs
    [Codecs.kicad_sch, DSP_Decoupling.kicad_sch, MCU.kicad_sch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]
2023-11-01 Wires DSP programming port to SPI instead of I2C
    [Codecs.kicad_sch, DSP_Decoupling.kicad_sch, MCU.kicad_sch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]
2023-11-02 Adds clock distributer
    [ClockDistribution.kicad_sch, Codecs.kicad_sch, DSP_Decoupling.kicad_sch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]
2023-11-05 Fixes minor issues
    [ClockDistribution.kicad_sch, Codecs.kicad_sch, DSP_Decoupling.kicad_sch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]
2023-11-14 adds usb to i2s bridge to micro. Adds tweaks for layout of maxi.
    [AnalogOutput.kicad_sch, Analog_Input.kicad_sch, Analog_Output.kicad_sch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]
2023-12-01 Fixes wrong connection in maxi schematic
    [ClockDistribution.kicad_sch, Codecs.kicad_sch, DSP_Decoupling.kicad_sch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]
2024-01-06 Adds final state of Maxi rev 1.0 and unbalanced IO boards rev 1.0.
    [AudioInputPCB_Unbalanced.kicad_sch, AudioOutputPCB_Unbalanced.kicad_sch, ClockDistribution.kicad_sch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]
2024-01-06 Adds a balanced input PCB for Maxi
    [AudioInputPCB_Balanced.kicad_sch, bom.csv, designators.csv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]
2024-01-17 Final commit before fabrication of: Maxi, Unbal In and Unbal Out Rev1.0
    [AudioInputPCB_Balanced.kicad_sch, AudioInputPCB_Unbalanced.kicad_sch, AudioOutputPCB_Balanced.kicad_sch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]

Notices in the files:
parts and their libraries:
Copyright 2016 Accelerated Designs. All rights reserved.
